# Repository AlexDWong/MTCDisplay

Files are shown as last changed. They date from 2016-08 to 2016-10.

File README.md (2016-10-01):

# MTCDisplay

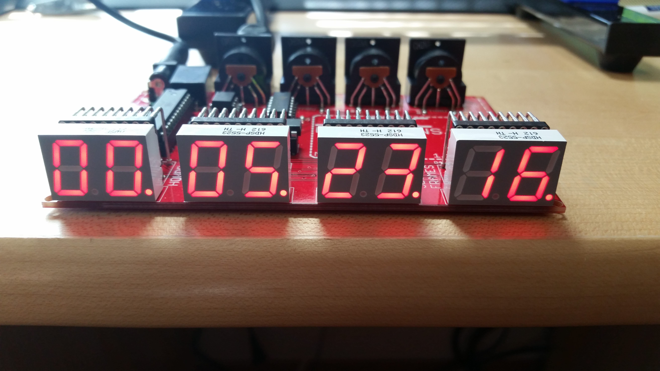
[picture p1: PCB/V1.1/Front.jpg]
Front


## Description
MTCDisplay is an Arduino-based MIDI Timecode visual display that allows users to view a MIDI Timecode stream on an external LED display. The goal of this project was to create a simple display to enable lighting, audio, and video equipment operators to visually monitor a timecode stream without spending $400+ on a fully-integrated solution.

## Updates
**9/28/2016:** Board version 1.1; see directory for changes.

**8/8/2016:** Board version 1.0 proven.

## Features
* MIDI IN/THRU (DIN-5 connector)
  * 1x MIDI IN
  * Up to 3x MIDI THRU
* 12VDC input with polarity and over-current protection
* Supports all MTC framerates (24, 25, 29.97, 30)
* Mounting holes for custom enclosures and edge clearance for extruded aluminum enclosures

## Physical
* Board Dimensions: 5.00" x 3.35" (127mm x 85.09mm)
* Board Thickness: 1.6mm
* Input Power: +12VDC, 1A (max)
* Input Connections: 2.1mm DC barrel jack, MIDI (DIN-5)
* Output Connections: Up to 3x MIDI (DIN-5)
* Mounting: 4x 0.125" holes at edges of board, 0.1" clearance on sides for insertion into extruded aluminum case

## How it works
MTCDisplay accepts input from a MIDI Timecode stream and displays it on a large, 7-segment display. The displays are driven and controlled by a MAX7219 driver, enabling the Arduino to focus on decoding the MIDI Timecode stream. MTCDisplay supports all four MTC framerates (24/25/29.97 drop-frame/30 frames/s), and the design can be scaled up to support almost any 7-segment, common-cathode LED display.

### "What's (MIDI) Timecode?"

Timecode is a way to synchronize equipment with each other; for instance, an audio track could output a timecode stream to a lighting console so that lighting cues are triggered at exactly the right moment. [MIDI Timecode (MTC)](https://en.wikipedia.org/wiki/MIDI_timecode) is timecode transmitted between devices using the MIDI protocol and interface, and is based off [SMPTE Timecode](https://en.wikipedia.org/wiki/SMPTE_timecode). 

You can read more about the MIDI protocol on [Wikipedia](https://en.wikipedia.org/wiki/MIDI) or on the [official MIDI Association website](https://www.midi.org/). 

### MIDI Timecode

MIDI Timecode follows the SMPTE standard for timecode. Each timecode is represented as four 8-bit unsigned integers:
* Hours (hh)
* Minutes (mm)
* Seconds (ss)
* Frames (ff)

Hours, minutes and seconds are self-explanatory. Frames are sub-divisions of seconds, originally referring to a frame of film as SMPTE timecode was originally developed for film use. There are several different framerates, and as a result MIDI Timecode must also transmit the framerate to ensure all devices are kept in sync.

MIDI Timecode messages can take one of two forms:

#### Quarter-frame Timecode

Quarter-frame Timecode messages are used when the timecode stream is running. Each hour, minute, second or frame byte is broken down into two 4-bit values and attached to a 3-bit identifier. Before each piece is sent, it is preceded by a single status byte (0xF1).

| Piece |  ID #  |  Data  |  Full Byte  | Description |
|:-----:|:---:|:---:|:---:|---|
| 0 | `0000` | `ffff` | `0000 ffff` | Frame number lsbits |
| 1 | `0001` | `000f` | `0001 000f` | Frame number msbit  |
| 2 | `0010` | `ssss` | `0010 ssss` | Seconds lsbits |
| 3 | `0011` | `00ss` | `0011 00ss` | Seconds msbits |
| 4 | `0100` | `mmmm` | `0100 mmmm` | Minutes lsbits |
| 5 | `0101` | `00mm` | `0101 00mm` | Minutes msbits |
| 6 | `0110` | `hhhh` | `0110 hhhh` | Hour lsbits |
| 7 | `0111` | `0rrh` | `0111 0rrh` | Hour msbit and rate |

**EX:** Timecode = 01:02:03:04, framerate = 30 frames/s

Quarter-frame Timecode = `F1 04 F1 10 F1 23 F1 30 F1 42 F1 50 F1 61 F1 76`

*Source: [Wikipedia](https://en.wikipedia.org/wiki/MIDI_timecode)*

#### Full Timecode

If the timecode stream suddenly jumps (i.e. jumping ahead in an audio track) a full timecode is sent so that all equipment can resync. Full timecode messages are 10 bytes long, and once transmitted the MTC stream reverts back to quarter-frame messages; full timecode messages are structured as follows:
	`F0 7F 7F 01 01 hh mm ss ff F7`
In it's current state, MTCDisplay only supports quarter-frame messages. If the timecode input jumps, the change will not be reflected on MTCDisplay until the next quarter-frame message is received.

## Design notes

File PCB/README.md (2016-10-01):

#PCB Files

Enclosed here are the files needed to have a PCB manufactured, as well as a Bill of Materials.

## Important Note:
The LED displays do not need a current-limiting resistor; instead, the current is set by an external pullup resistor on the MAX7219. If you choose to use a different 7-segment display, then you may need to select a different value for R12 depending on the per-segment forward voltage and foward current. The [MAX7219 datasheet (PDF)](https://datasheets.maximintegrated.com/en/ds/MAX7219-MAX7221.pdf) contains a table with approximate resistance values for a range of voltages and currents; when in doubt, a higher resistance is better.

## Versions
### Version 1.1
Resolved several issues:
* All capacitors have been replaced with 0805 SMD ceramic variants to reduce board space.
* Board reduced in size slightly.
* Rearranged components for easier hand-soldering.
* LCD display package has been corrected; displays now protrude slightly over the edge of the board instead of being inset 1/4" from the edge.
* MIDI OUT/THRU switch removed; no plans to add MTC output at this time.
* Fixed silkscreen part names and text placement.
* Added 0603 LED for power indication.
* Added 0.100", 2x3 ICSP header to program Arduino directly.
* Added diode to RESET signal for ICSP support.
* Added reverse-polarity and over-current protection to input.

### Version 1.0
Initial release. This version has been tested and is proven to work as described. Only Gerber files and a BOM are included.

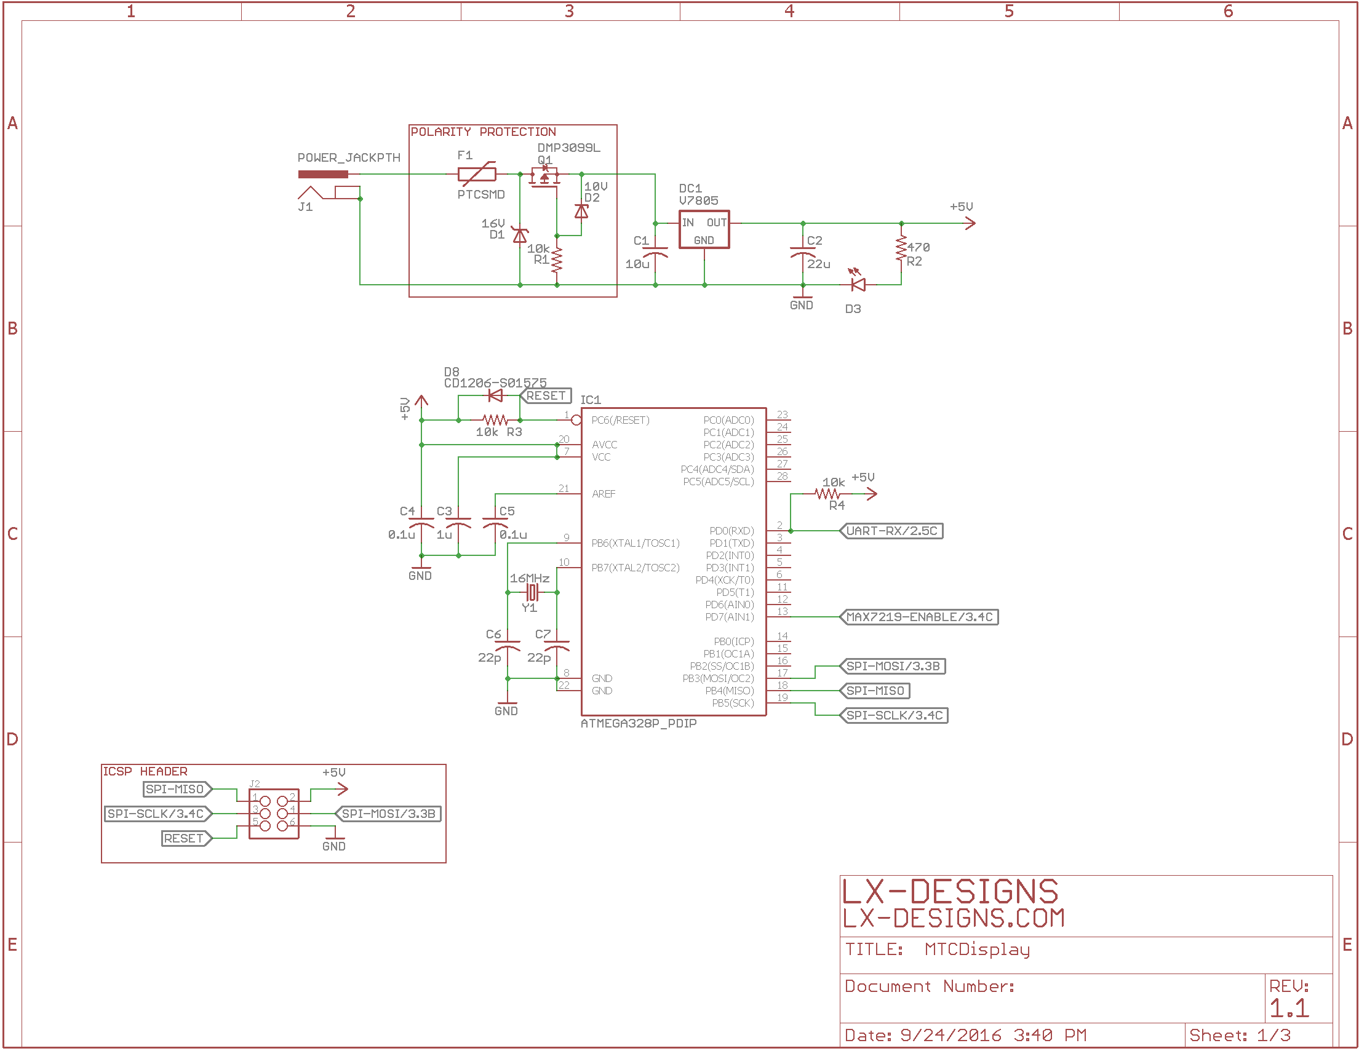
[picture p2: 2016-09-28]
PCB/V1.1/Schematic1.png

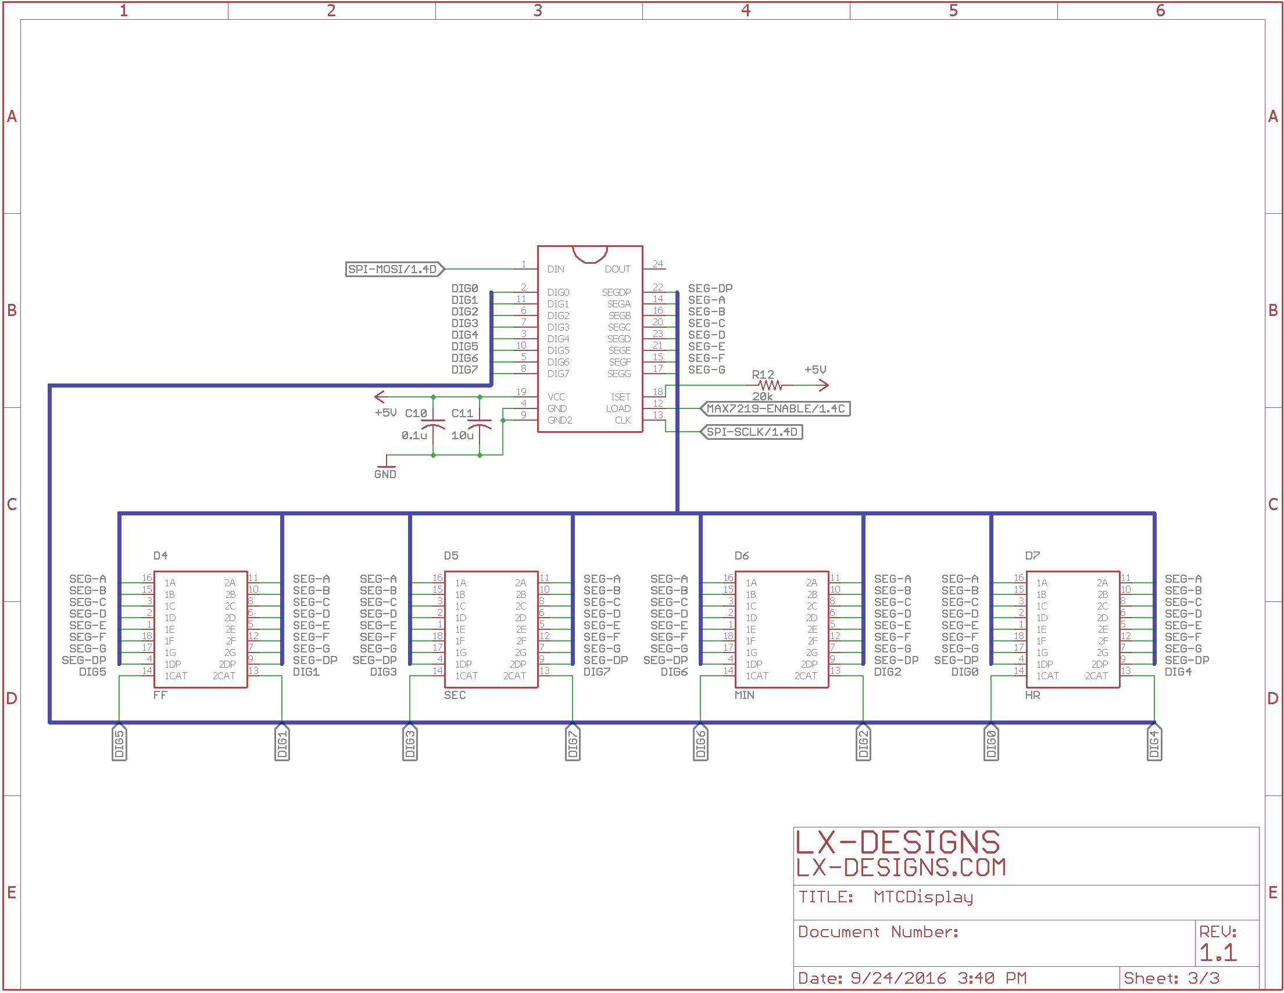
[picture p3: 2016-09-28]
PCB/V1.1/Schematic3.png

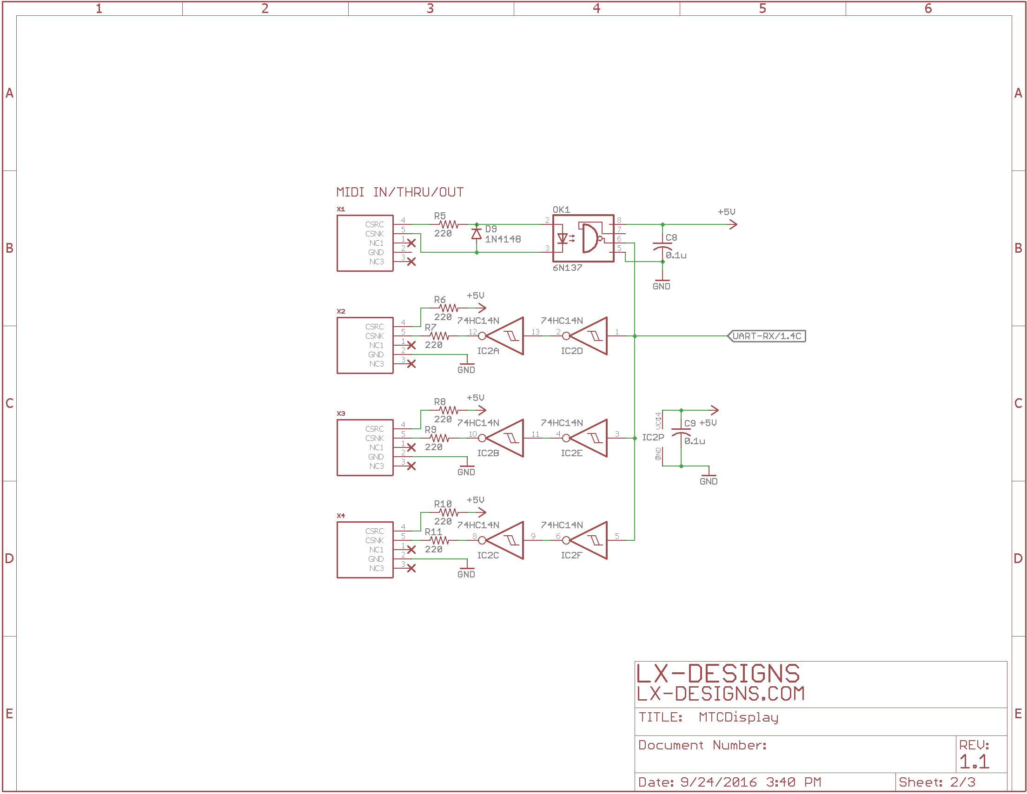
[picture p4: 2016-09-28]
PCB/V1.1/Schematic2.png

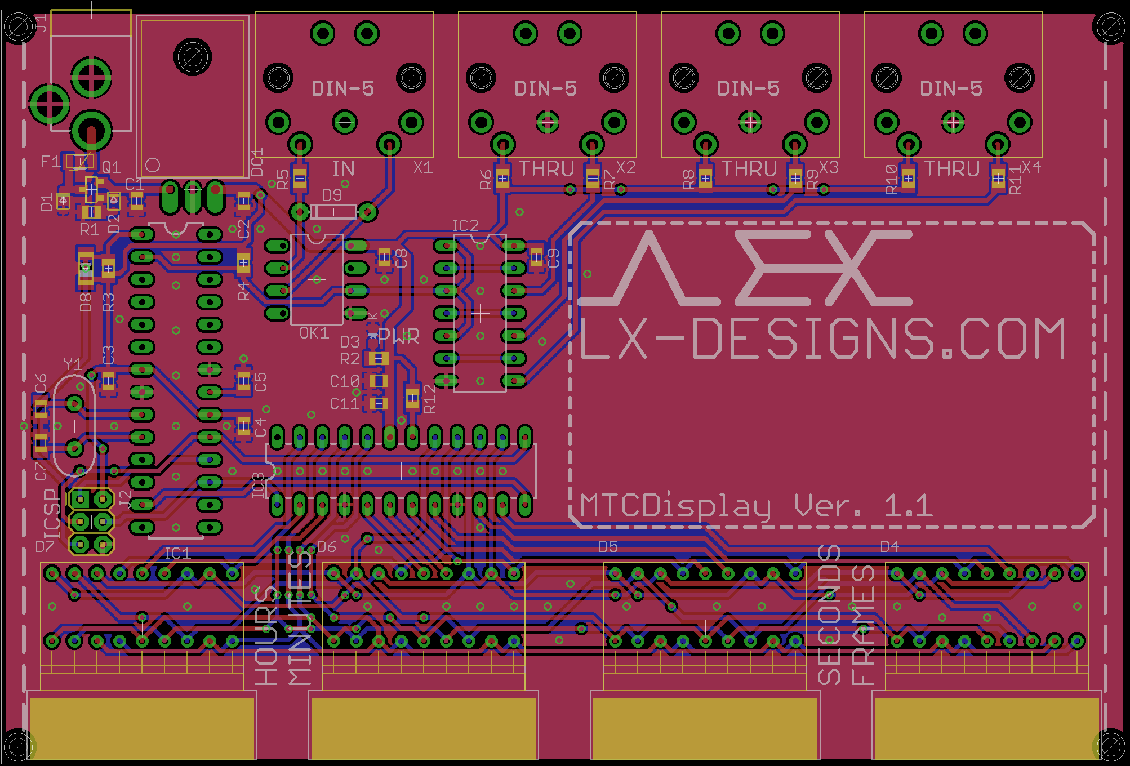
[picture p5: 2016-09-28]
PCB/V1.1/Board.png

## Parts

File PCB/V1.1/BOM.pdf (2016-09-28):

Item | Ref | Qty | Description | Mfg | Part Number
1 | C1, C11 | 2 | Capacitor, 10uF, 25V, 10%, 0805 X5R | Murata | GRM21BR61E106KA73L
2 | C2 | 1 | Capacitor, 22uF, 16V, 20%, 0805 X5R | Samsung | CL21A226MOCLRNC
3 | C3 | 1 | Capacitor, 1uF, 16V, 10%, 0805 X7R | Yageo | CC0805KKX7R7BB105
4 | C4, C5, C8, C9, C10 | 5 | Capacitor, 0.1uF, 50V, 10%, 0805 X7R | Yageo | CC0805KRX7R9BB104
5 | C6, C7 | 2 | Capacitor, 22pF, 50V, 5%, 0805 | Yageo | CC0805JRNPO9BN220
6 | D1 | 1 | TVS Diode, 1-channel Unidirectional, 24V, SOD323 | NXP | PESD24VL1BA,115
7 | D2 | 1 | Zener Diode,7.5V, 2%, 200mW, SOD-323 | ON Semiconductor | MM3Z7V5ST1G
8 | D3 | 1 | LED 2.1V/10mA, 0603 | Lite-On Inc. | LTST-C129GKT
9 | D4, D5, D6, D7 | 4 | Connector, 0.600" DIP, 2x9, Right-Angle | Mill-Max | 299-43-618-10-002000
10 | D4, D5, D6, D7 | 4 | LED,7-segment + DP Display, 2.1V/20mA, DIP-18 0.600" | Broadcom | HDSP-5523
11 | D8 | 1 | Diode, 1V, 1206 | Bourns | CD1206-S01575
12 | D9 | 1 | Diode, 1N4148, 1V, Through-Hole | Fairchild | 1N4148
13 | DC1 | 1 | DC/DC Converter, Non-Isolated, 7-18Vin/5Vout, 10W, SIP-3 Right Angle | CUI Inc | V7805-2000R
14 | F1 | 1 | PTC Fuse, 24V, 500mA/1A, 1206 | Bel Fuse Inc | 0ZCJ0050AF2E
15 | IC1 | 1 | IC, MCU, AVR, 20MHz, 32KB, DIP-28 | Atmel | ATMEGA328P-PN
16 | IC2 | 1 | IC, Inverter, 6-Channel Schmitt Trigger, DIP-14 | Texas Instruments | SN74HC14N
17 | IC3 | 1 | IC, Display Driver, 7-Segment + DP, 8-digit, SPI, DIP-24 | Maxim Integrated | MAX7219CNG+
18 | J1 | 1 | Connector, DC Power Jack, 2.10mm, Right-Angle Through Hole | MPD | EJ508A
19 | J2 | 1 | Connector, Breakaway, 0.100", 3x2, Through-Hole | TE Connectivity | 5-5176264-8
20 | OK1 | 1 | Optocoupler, 1-channel, 15MBd, DIP-8 | Lite-On Inc. | 6N137
21 | Q1 | 1 | MOSFET, P-channel, 30V, 65mOhm, SOT-23 | Diodes Incorporated | DMP3099L-7
22 | R1, R3, R4 | 3 | Resistor, 10K, 0.125W, 5%, 0805 | Stackpole | RMCF0805JT10K0
23 | R2 | 1 | Resistor, 470, 0.1W, 1%, 0805 | Stackpole | RMCF0805FT470R
24 | R5, R6, R7, R8, R9, R10, R11 | 7 | Resistor, 220, 0.125W, 5%, 0805 | Stackpole | RMCF0805JT220R
25 | R12 | 1 | Resistor, 20K, 0.125W, 1%, 0805 | Yageo | RC0805FR-0720KL
26 | X1, X2, X3, X4 | 4 | Connector, DIN, 5-position, Female, Right-Angle PCB | CUI Inc | SDS-50J
27 | Y1 | 1 | Crystal, 16MHz, 10ppm, 18pF, HC49/US | TXC | 9B-16.000MEEJ-B
Item | Ref | Qty | Description | Mfg | Part Number
28 | IC1 | 1 | Connector, IC Socket, DIP-28 0.300" | On Shore Technology | ED28DT
29 | IC2 | 1 | Connector, IC Socket, DIP-14 0.300" | On Shore Technology | ED14DT

PCB Do Not Populate (User-Discresion)

30 | IC3 | 1 | Connector, IC Socket, DIP-24 0.300" | On Shore Technology | ED24DT
31 | OK1 | 1 | Connector, IC Socket, DIP-8 0.300" | On Shore Technology | ED08DT

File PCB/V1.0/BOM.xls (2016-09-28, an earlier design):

Digi-Key Part Number | Manufacturer | Manufacturer Part Number | Customer Reference | Quantity | Mfg Std Lead Time | Description
1N4148FS-ND | FAIRCHILD SEMICONDUCTOR | 1N4148 | D9 | 1 | 16 Weeks | DIODE GEN PURP 100V 200MA DO35
478-4855-ND | AVX CORPORATION | SR201C104KAR | C4, C5, C8, C9, C10 | 5 | 12 Weeks | CAP CER 0.1UF 100V X7R RADIAL
P5134-ND | PANASONIC ELECTRONIC COMPONENTS | ECA-1CM100 | C1, C11 | 2 | 14 Weeks | CAP ALUM 10UF 20% 16V RADIAL
311-20.0KCRCT-ND | YAGEO (VA) | RC0805FR-0720KL | R10 | 1 | 22 Weeks | RES SMD 20K OHM 1% 1/8W 0805
478-3162-ND | AVX CORPORATION | SR152A220KAR | C6, C7 | 2 | 19 Weeks | CAP CER 22PF 200V NP0 RADIAL
P15803CT-ND | PANASONIC ELECTRONIC COMPONENTS (VA) | EEA-GA1E220H | C2 | 1 | 18 Weeks | CAP ALUM 22UF 20% 25V RADIAL
ATMEGA328P-PN-ND | ATMEL | ATMEGA328P-PN | U1 | 1 | 6 Weeks | IC MCU 8BIT 32KB FLASH 28PDIP
EJ508A-ND | MEMORY PROTECTION DEVICES | EJ508A | J1 | 1 | 12 Weeks | DC JACK W/SOLDER LUGS PCB MOUNT
102-2188-ND | CUI INC | V7805-2000R | G1 | 1 | 10 Weeks | CONVERT DC/DC REG 5V 2000MA R/A
887-1244-ND | TXC CORPORATION | 9B-16.000MEEJ-B | Y1 | 1 | 13 Weeks | CRYSTAL 16.0000MHZ 18PF T/H
478-7667-ND | AVX CORPORATION | SR205E105MAR | C3 | 1 | 12 Weeks | CAP CER 1UF 50V Z5U RADIAL
RMCF0805JT220RCT-ND | STACKPOLE ELECTRONICS INC (VA) | RMCF0805JT220R | R1, R2, R3, R4, R5, R6, R7 | 10 | 11 Weeks | RES SMD 220 OHM 5% 1/8W 0805
EG1903-ND | E-SWITCH | EG1218 | S1 | 1 | 12 Weeks | SWITCH SLIDE SPDT 200MA 30V
RMCF0805JT10K0CT-ND | STACKPOLE ELECTRONICS INC (VA) | RMCF0805JT10K0 | R8, R9 | 2 | 11 Weeks | RES SMD 10K OHM 5% 1/8W 0805
160-1791-ND | LITE-ON INC | 6N137 | OK1 | 1 | 10 Weeks | OPTOISO 5KV OPEN COLLECTOR 8DIP
296-1577-5-ND | TEXAS INSTRUMENTS | SN74HC14N | IC1 | 1 | 6 Weeks | IC HEX SCHMITT-TRIG INV 14-DIP
516-1217-5-ND | BROADCOM LIMITED | HDSP-5523 | D1, D2, D3, D4 | 4 | 5 Weeks | LED 7-SEG 14.2MM 2DIG CC HER RHD
CP-2350-ND | CUI INC | SDS-50J | U2, U3, U4, U5 | 4 | 8 Weeks | CONN DIN 5 PIN FEMALE PCB
ED3050-5-ND | ON SHORE TECHNOLOGY INC | ED281DT | U1 | 1 | 8 Weeks | CONN IC DIP SOCKET 28POS TIN
ED3049-5-ND | ON SHORE TECHNOLOGY INC | ED241DT | U6 | 1 | 8 Weeks | CONN IC DIP SOCKET 24POS TIN
ED3045-5-ND | ON SHORE TECHNOLOGY INC | ED14DT | IC1 | 1 | 8 Weeks | CONN IC DIP SOCKET 14POS TIN
ED3044-5-ND | ON SHORE TECHNOLOGY INC | ED08DT | OK1 | 1 | 8 Weeks | CONN IC DIP SOCKET 8POS TIN
ED90147-ND | MILL-MAX MANUFACTURING CORP | 299-43-618-10-002000 | D1, D2, D3, D4 | 4 | 4 Weeks | CONN IC DIP SOCKET 18POS GOLD
MAX7219CNG+-ND | MAXIM INTEGRATED | MAX7219CNG+ | U6 | 1 | 8 Weeks | IC DRIVER LED DISPLAY 8DGT 24DIP

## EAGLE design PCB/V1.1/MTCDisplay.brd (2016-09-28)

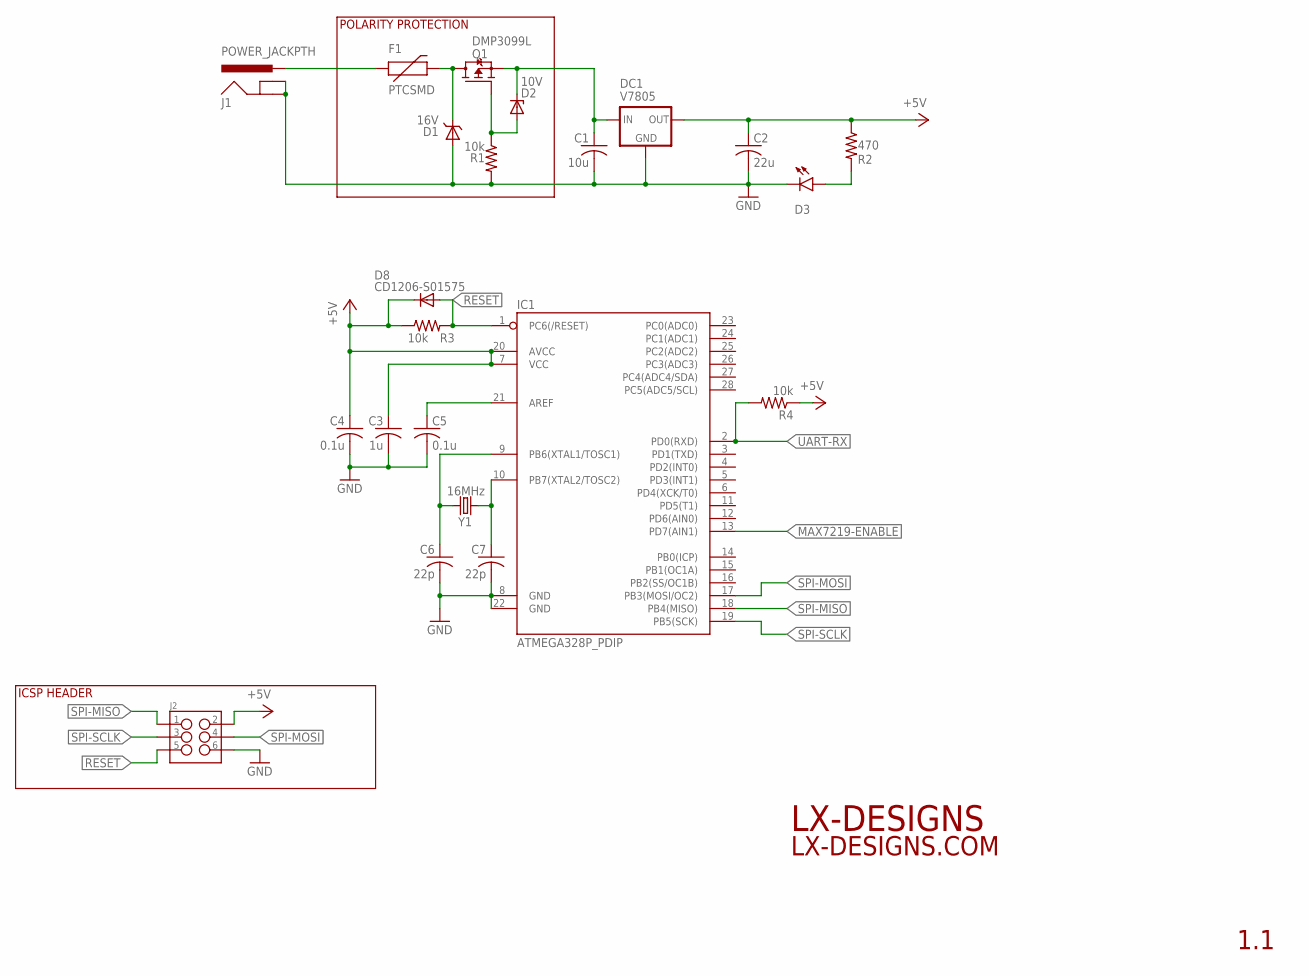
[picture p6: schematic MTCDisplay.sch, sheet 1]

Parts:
C1: 10u; C0805K
C2: 22u; C0805K
C3: 1u; C0805K
C4, C5: 0.1u; C0805K
C6, C7: 22p; C0805K
D1: 16V; SOD323-NOSILK
D2: 10V; SOD323
D3: LED0603; LED-0603
D8: CD1206-S01575; MINIMELF
DC1: V7805
F1: PTCSMD; PTC-1206
IC1: ATMEGA328P_PDIP; DIL28-3
J1: POWER_JACKPTH; POWER_JACK_PTH
J2: M03X2NO_SILK; 2X3-NS
Q1: DMP3099L; SOT23
R1, R3, R4: 10k; R0805
R2: 470; R0805
Y1: 16MHz; HC49US

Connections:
5V: C1.1, D2.C, DC1.IN, Q1.2 (S)
+5V: C2.1, C3.1, C4.1, D8.C, DC1.OUT, IC1.7 (VCC), IC1.20 (AVCC), J2.2, R2.1, R3.1, R4.1; also elsewhere on the board
GND: C1.2, C2.2, C3.2, C4.2, C5.2, C6.2, C7.2, D1.A, D3.C, DC1.GND, IC1.8 (GND), IC1.22 (GND), J1.GND, J1.GNDBREAK, J2.6, R1.2; also elsewhere on the board
MAX7219-ENABLE: IC1.13 (PD7(AIN1)); also elsewhere on the board
unnamed: C6.1, IC1.9 (PB6(XTAL1/TOSC1)), Y1.2
unnamed: C5.1, IC1.21 (AREF)
unnamed: D3.A, R2.2
unnamed: C7.1, IC1.10 (PB7(XTAL2/TOSC2)), Y1.1
unnamed: F1.1, J1.PWR
unnamed: D1.C, F1.2, Q1.3 (D)
unnamed: D2.A, Q1.1 (G), R1.1
RESET: D8.A, IC1.1 (PC6(/RESET)), J2.5, R3.2
SPI-MISO: IC1.18 (PB4(MISO)), J2.1
SPI-MOSI: IC1.17 (PB3(MOSI/OC2)), J2.4; also elsewhere on the board
SPI-SCLK: IC1.19 (PB5(SCK)), J2.3; also elsewhere on the board
UART-RX: IC1.2 (PD0(RXD)), R4.2; also elsewhere on the board

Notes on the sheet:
POLARITY PROTECTION
ICSP HEADER
LX-DESIGNS
LX-DESIGNS.COM
1.1

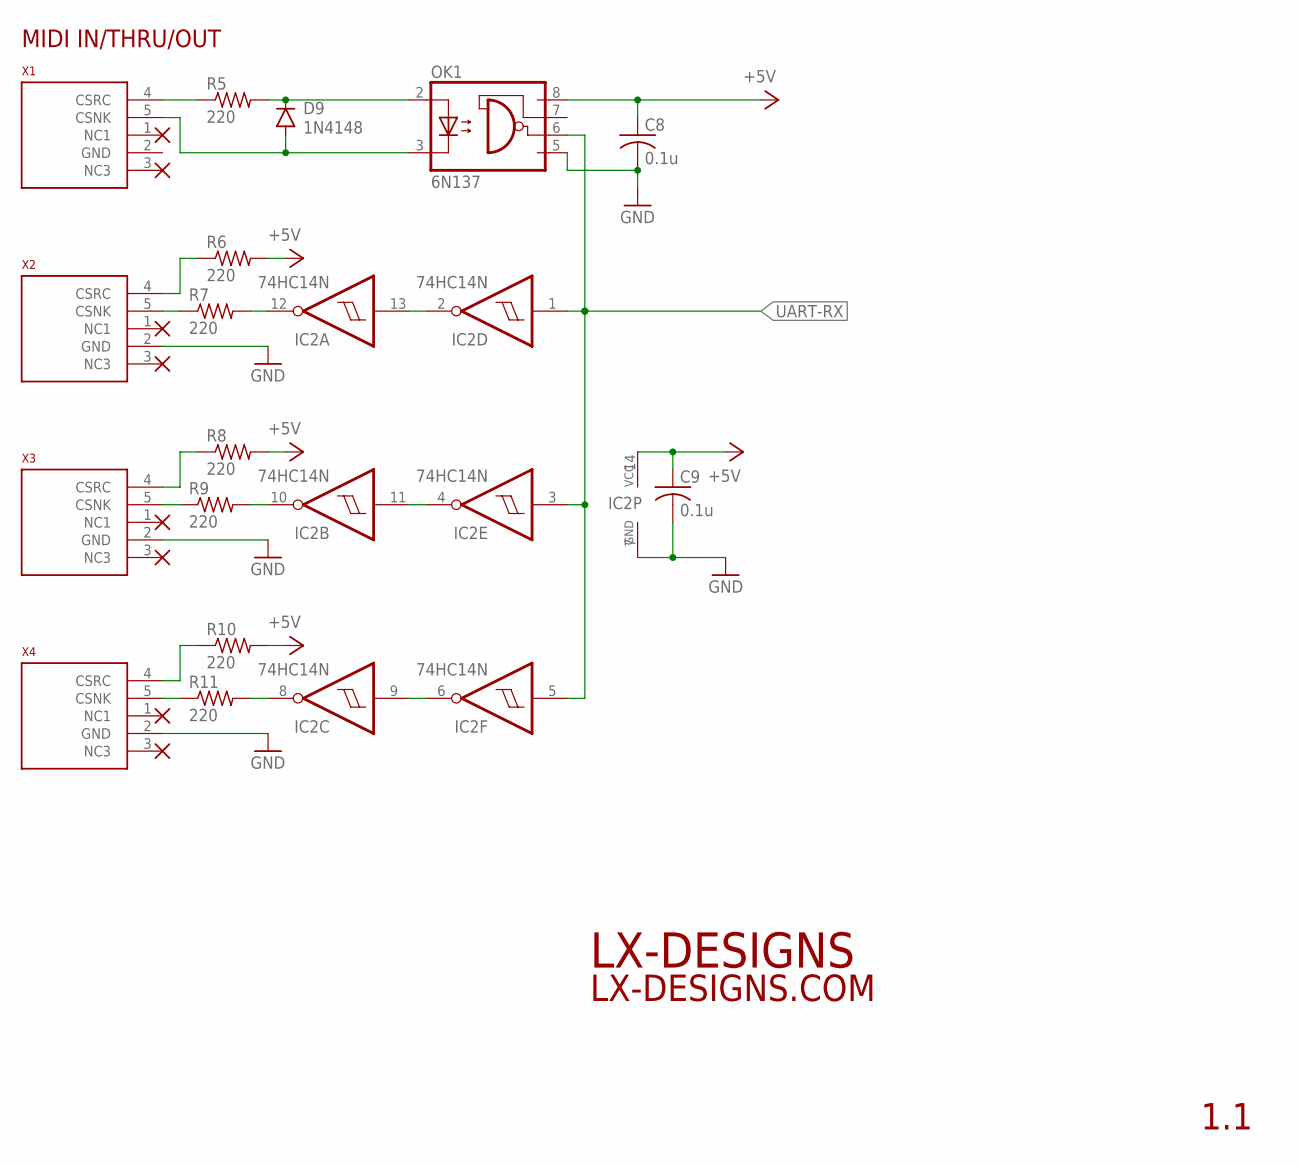
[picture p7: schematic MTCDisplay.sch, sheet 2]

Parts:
C8, C9: 0.1u; C0805K
D9: 1N4148; DIODE-1N4148
IC2: 74HC14N; DIL14
OK1: 6N137; DIL08
R5, R6, R7, R8, R9, R10, R11: 220; R0805
X1, X2, X3, X4: 57PC5FSWITCHCRAFT; DIN_5_FEMALE_SUPPORT

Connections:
+5V: C8.1, C9.1, IC2.14 (VCC), OK1.8 (VCC), R6.2, R8.2, R10.2; also elsewhere on the board
GND: C8.2, C9.2, IC2.7 (GND), OK1.5 (GND), X2.2 (GND), X3.2 (GND), X4.2 (GND); also elsewhere on the board
unnamed: R5.1, X1.4 (CSRC)
unnamed: D9.C, OK1.2 (A), R5.2
unnamed: D9.A, OK1.3 (C), X1.5 (CSNK)
unnamed: IC2.2 (O), IC2.13 (I)
unnamed: IC2.12 (O), R7.2
unnamed: IC2.10 (O), R9.2
unnamed: R7.1, X2.5 (CSNK)
unnamed: R6.1, X2.4 (CSRC)
unnamed: IC2.8 (O), R11.2
unnamed: R9.1, X3.5 (CSNK)
unnamed: R8.1, X3.4 (CSRC)
unnamed: IC2.4 (O), IC2.11 (I)
unnamed: IC2.6 (O), IC2.9 (I)
unnamed: R11.1, X4.5 (CSNK)
unnamed: R10.1, X4.4 (CSRC)
UART-RX: IC2.1 (I), IC2.3 (I), IC2.5 (I), OK1.6 (VO); also elsewhere on the board

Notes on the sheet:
MIDI IN/THRU/OUT
LX-DESIGNS
LX-DESIGNS.COM
1.1

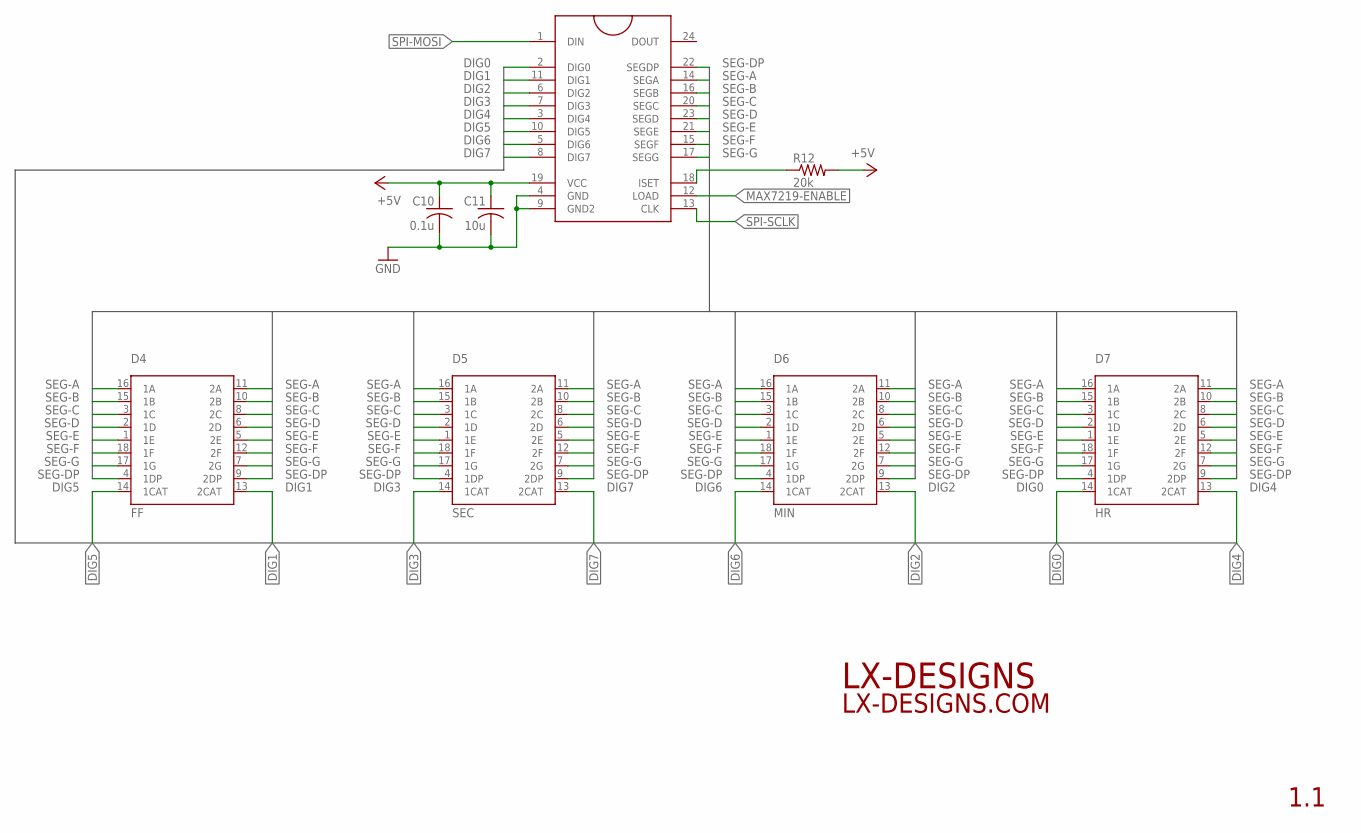
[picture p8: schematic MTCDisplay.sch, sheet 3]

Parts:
C10: 0.1u; C0805K
C11: 10u; C0805K
D4: FF; 299-XX-43-618-10-002000
D5: SEC; 299-XX-43-618-10-002000
D6: MIN; 299-XX-43-618-10-002000
D7: HR; 299-XX-43-618-10-002000
IC3: MAX7219DIP; DIL24
R12: 20k; R0805

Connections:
+5V: C10.1, C11.1, IC3.19 (VCC), R12.2; also elsewhere on the board
DIG0: D7.14 (1CAT), IC3.2 (DIG0)
DIG1: D4.13 (2CAT), IC3.11 (DIG1)
DIG2: D6.13 (2CAT), IC3.6 (DIG2)
DIG3: D5.14 (1CAT), IC3.7 (DIG3)
DIG4: D7.13 (2CAT), IC3.3 (DIG4)
DIG5: D4.14 (1CAT), IC3.10 (DIG5)
DIG6: D6.14 (1CAT), IC3.5 (DIG6)
DIG7: D5.13 (2CAT), IC3.8 (DIG7)
GND: C10.2, C11.2, IC3.4 (GND), IC3.9 (GND2); also elsewhere on the board
MAX7219-ENABLE: IC3.12 (LOAD); also elsewhere on the board
unnamed: IC3.18 (ISET), R12.1
SEG-A: D4.11 (2A), D4.16 (1A), D5.11 (2A), D5.16 (1A), D6.11 (2A), D6.16 (1A), D7.11 (2A), D7.16 (1A), IC3.14 (SEGA)
SEG-B: D4.10 (2B), D4.15 (1B), D5.10 (2B), D5.15 (1B), D6.10 (2B), D6.15 (1B), D7.10 (2B), D7.15 (1B), IC3.16 (SEGB)
SEG-C: D4.3 (1C), D4.8 (2C), D5.3 (1C), D5.8 (2C), D6.3 (1C), D6.8 (2C), D7.3 (1C), D7.8 (2C), IC3.20 (SEGC)
SEG-D: D4.2 (1D), D4.6 (2D), D5.2 (1D), D5.6 (2D), D6.2 (1D), D6.6 (2D), D7.2 (1D), D7.6 (2D), IC3.23 (SEGD)
SEG-DP: D4.4 (1DP), D4.9 (2DP), D5.4 (1DP), D5.9 (2DP), D6.4 (1DP), D6.9 (2DP), D7.4 (1DP), D7.9 (2DP), IC3.22 (SEGDP)
SEG-E: D4.1 (1E), D4.5 (2E), D5.1 (1E), D5.5 (2E), D6.1 (1E), D6.5 (2E), D7.1 (1E), D7.5 (2E), IC3.21 (SEGE)
SEG-F: D4.12 (2F), D4.18 (1F), D5.12 (2F), D5.18 (1F), D6.12 (2F), D6.18 (1F), D7.12 (2F), D7.18 (1F), IC3.15 (SEGF)
SEG-G: D4.7 (2G), D4.17 (1G), D5.7 (2G), D5.17 (1G), D6.7 (2G), D6.17 (1G), D7.7 (2G), D7.17 (1G), IC3.17 (SEGG)
SPI-MOSI: IC3.1 (DIN); also elsewhere on the board
SPI-SCLK: IC3.13 (CLK); also elsewhere on the board

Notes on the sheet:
LX-DESIGNS
LX-DESIGNS.COM
1.1

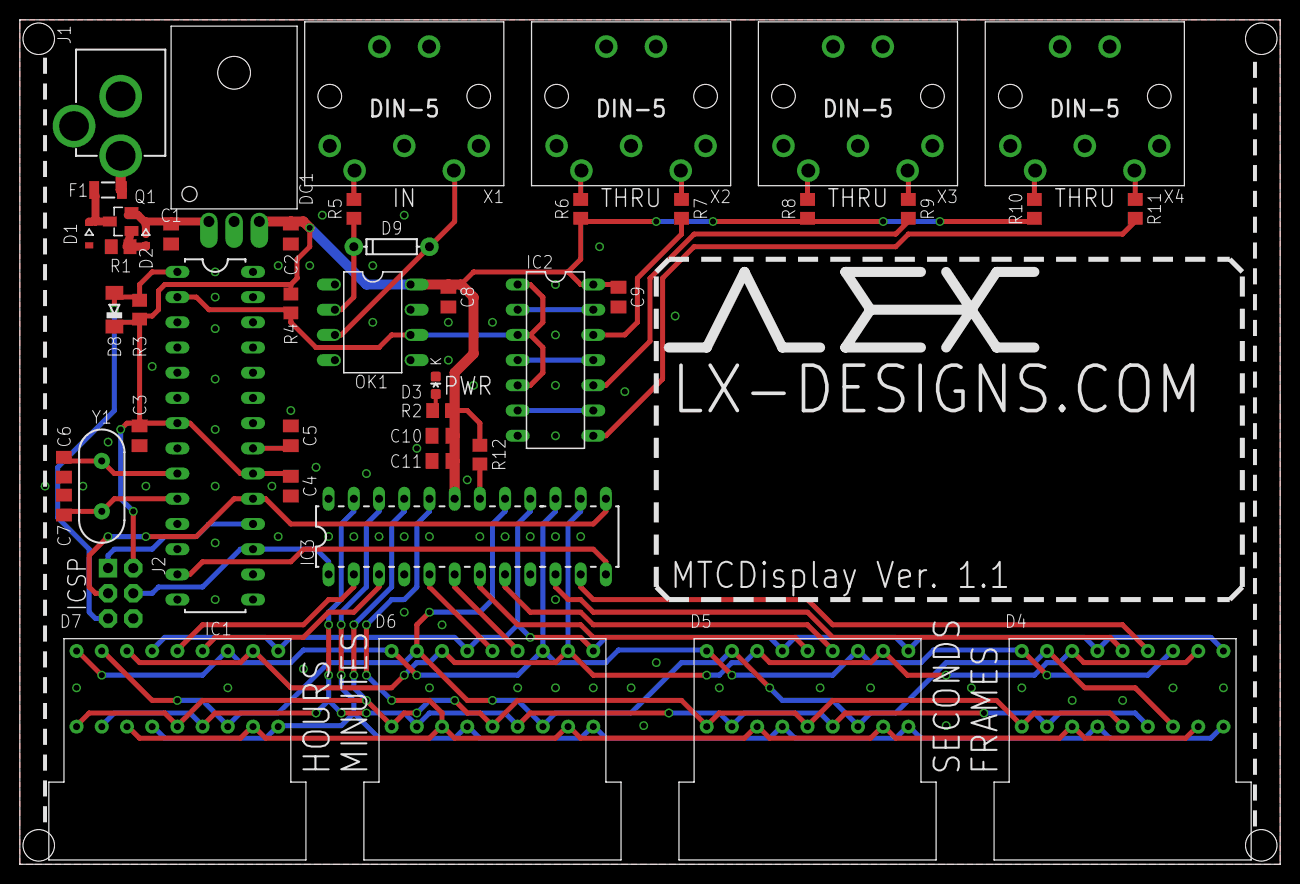
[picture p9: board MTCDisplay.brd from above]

Board: 2 copper layers, 127.0 x 85.1 mm, 46 parts (0 on the bottom side), 48 nets.

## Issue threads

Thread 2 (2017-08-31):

Lost frames

JLightMedia, 2017-08-31:
Hello! Thank you for this project! It's cool! I work with Arduino now and I want to create device to convert MTC to LTC. I've tried your sketch. It works good although I have one question. Why only even MTC frames detected and odd MTC frames just duplicate previous frame?

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

rdoursenaud, 2021-08-18:
I'm working on a similar project using a different display and red through the MTC specification carefully.
I guess this is due to a naive implementation relying only on a full MTC Quarter Frame message train (8 messages / 2 frames) received to display the result where the specification explicitly states that the first and fourth QF messages are sync points.
Be aware that you also have to know the direction to decide what to display and always should add or subtract 2 frames to the latest train received since when the message is complete, the information is 2 frames old.

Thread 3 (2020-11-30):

Midi Bars / Beats

NRKorsakov, 2020-11-30:
Hello Alex, and than you for this wonderful resource. I wanted to ask it if it possible to use this to display midi bars/beats instead of timecode? Thanks!!!

rdoursenaud, 2021-08-18:
You’d have to use another protocol. MTC can only transmit SMPTE timecode information.
My best guess would be Mackie’s HUI or MCU protocols.
This would require quite a bit of work!

NRKorsakov, 2021-08-18:
Hey thanks for the reply!

I'll try that.

Thanks again!

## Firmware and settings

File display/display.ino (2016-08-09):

/*
    Adapted from https://gist.github.com/nrdobie/8193350
*/

#include <SPI.h>
#include <stdio.h>

#define LOAD_PIN 7    //Load/CS pin

byte h, m, s, f;      //hours, minutes, seconds, frame
byte buf_temp[8];     //timecode buffer
byte command, data, index;

/*  Write VALUE to register ADDRESS on the MAX7219. */
void display_write(uint8_t address, uint8_t value) {
  digitalWrite(LOAD_PIN, LOW); //Toggle enable pin to load MAX7219 shift register
  SPI.transfer(address);
  SPI.transfer(value);
  digitalWrite(LOAD_PIN, HIGH); 
}


/*  Update Timecode display. Called once FRAMES LSB quarter-frame received to
      avoid writing to chip every single time.
*/
void display_timecode() {   
  display_write(0x02, ((f%10)|0x80)); //enable decimal point on LSB
  display_write(0x06, (f/10));        
  display_write(0x08, ((s%10)|0x80)); 
  display_write(0x04, (s/10));
  display_write(0x03, ((m%10)|0x80));
  display_write(0x07, (m/10));
  display_write(0x05, ((h%10)|0x80));
  display_write(0x01, (h/10));
}

void setup() {
  pinMode(LOAD_PIN, OUTPUT);  //Load/CS pin output
  SPI.setBitOrder(MSBFIRST);  //MSB first
  SPI.begin();
  
  Serial.begin(31250, SERIAL_8N1); //MIDI input 

  //test by turning on, then off
  display_write(0x0F, 0x01);
  delay(1000);
  display_write(0x0F, 0x00);

  display_write(0x09, 0xFF);  //enable onboard bit decode (Mode B)
  display_write(0x0A, 0x0F);  //max intensity
  display_write(0x0B, 0x07);  //display all digits
  display_write(0x0C, 0x01);  //turn on chip

  //display all zeros, and add decimal points to LSB
  for (int i = 0x01; i <= 0x08; ++i) {
    display_write(i, 0x00);
  }
  display_write(0x05, 0x80);  //
  display_write(0x03, 0x80);
  display_write(0x08, 0x80);
  display_write(0x02, 0x80);
  
}

/*  Instead of using a while() loop, reduce power usage and increase performance using a UART interrupt handler.
      When a quarter-frame TC packet is received, update the internal timecode buffer.
      When the FRAMES LSB quarter-frame is received, also update the visual display.
*/
void serialEvent() {
  if (Serial.available() > 1) {
    command = Serial.read();
    if (command != 0xF1) {    //realign quarter-frame packets
      command = Serial.read();
    }
    data = Serial.read();
    index = data >> 4;  //extract index/packet ID
    data &= 0x0F;       //clear packet ID from data
    buf_temp[index] = data;
  }

  if (index >= 0x07) {  //recalculate timecode once FRAMES LSB quarter-frame received
    h = (buf_temp[7] & 0x01)*16 + buf_temp[6];
    m = buf_temp[5]*16 + buf_temp[4];
    s = buf_temp[3]*16 + buf_temp[2];
    f = buf_temp[1]*16 + buf_temp[0];
    display_timecode();
  }
}

void loop() {
}
  

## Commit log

2016-08-04 PCB Gerber files rev 1.0
    [MTCDisplay.GBL, MTCDisplay.GBO, MTCDisplay.GBS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]
2016-08-09 updated register/digit mapping to match PCB trace layout
2016-08-09 New PCB revision
    [MTCDisplay.brd, MTCDisplay.sch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]
2016-08-09 include BOM
    [BOM.xls]
2016-08-09 update v1.1 schematics (replace 0.1uF cap package, add part names)
    [MTCDisplay.brd, MTCDisplay.sch]
2016-08-29 Update segment display package
    [MTCDisplay.brd, MTCDisplay.sch]
2016-08-30 Remove MIDI OUT, replace all TH capacitor with SMD
    [MTCDisplay.brd, MTCDisplay.sch]
2016-09-28 Revision 1.1 proven
    [MTCDisplay.brd, MTCDisplay.sch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]
2016-09-28 Clean directories
    [BOM.xls, MTCDisplay.brd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]
2016-09-28 V1.0 BOM
    [BOM.xls]
2016-09-28 Remove EAGLE-generated BOM
2016-09-28 Board/Schematic images
2016-10-01 Renumber schematic PNGs

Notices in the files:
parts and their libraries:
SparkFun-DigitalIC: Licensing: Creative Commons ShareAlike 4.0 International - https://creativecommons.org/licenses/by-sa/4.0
